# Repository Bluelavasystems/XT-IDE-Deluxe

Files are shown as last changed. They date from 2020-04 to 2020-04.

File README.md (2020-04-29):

Blue lava systems XT-IDE Deluxe ReadMe
----

Bootable 8-bit ISA CF+IDE interface

Documentation for the switches can be found on the rear silkscreen.

Credit:
----
Design by monotech pcs

Design uses some of the schematic from XT-IDE Rev2 and Glitchworks
www.vcfed.org/forum/showthread.php?29202-XTIDE-Rev2
github.com/glitchwrks/xt_ide

XT-IDE Universal BIOS
www.xtideuniversalbios.org

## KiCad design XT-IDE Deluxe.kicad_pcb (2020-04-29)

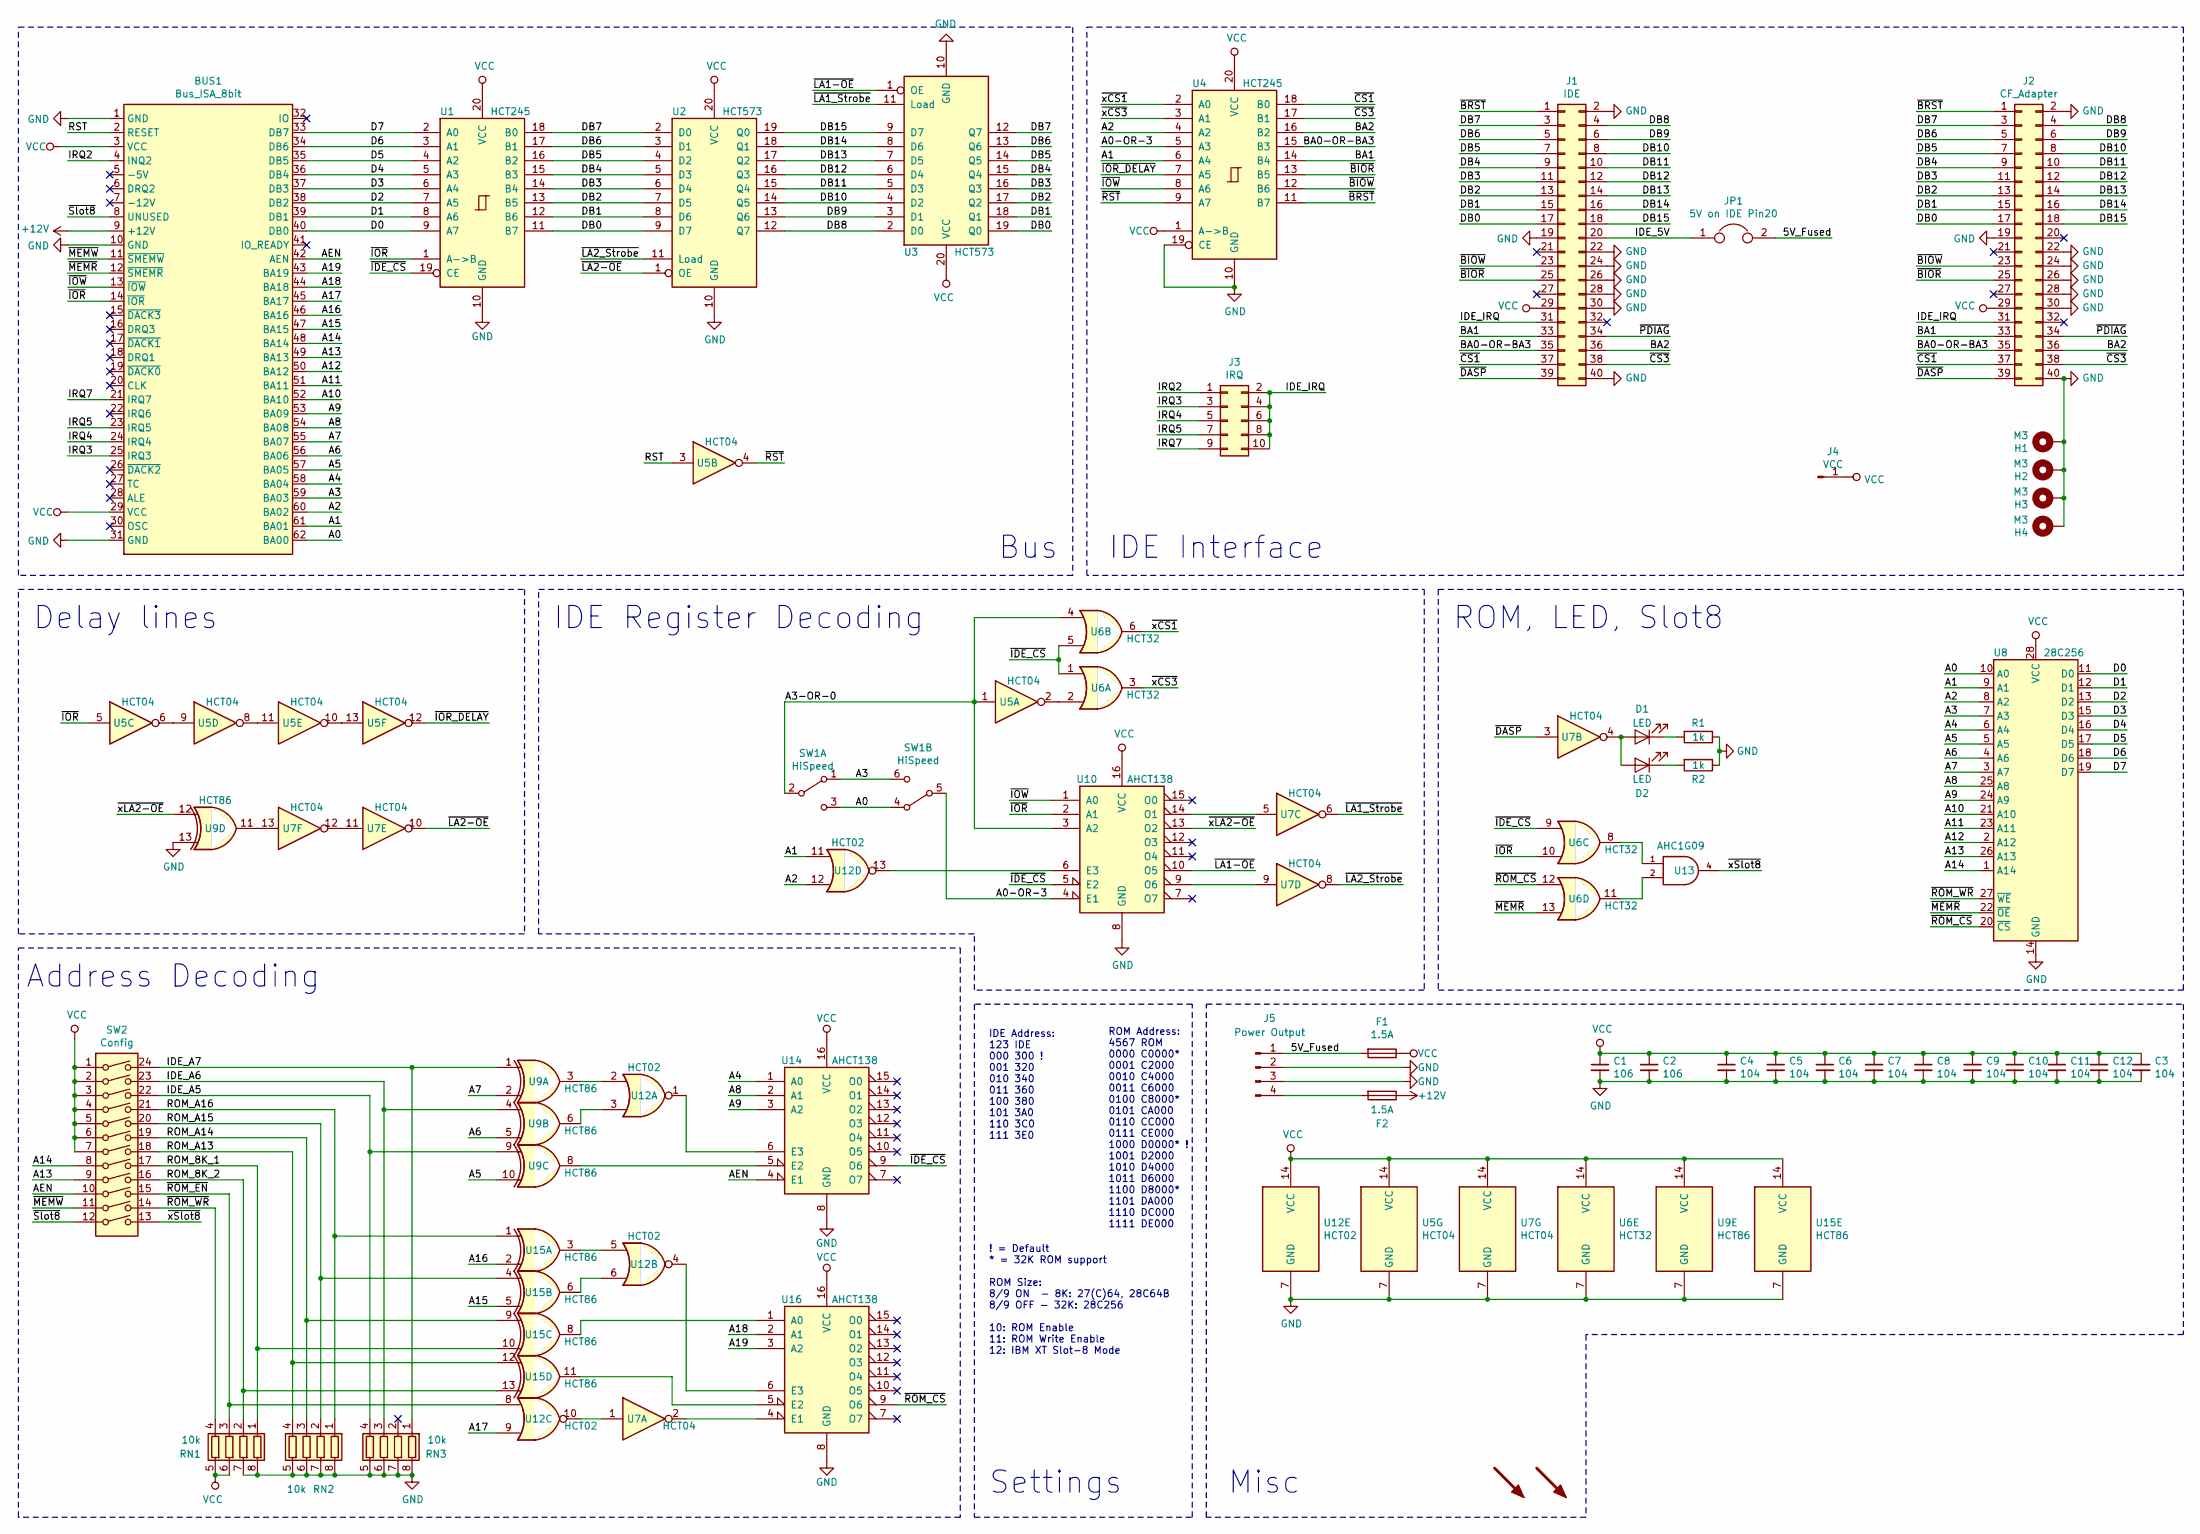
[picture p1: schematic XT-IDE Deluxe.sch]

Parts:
BUS1: Bus_ISA_8bit; ISA-8BIT-XT-IDE
C1, C2: 106; C_0805_2012Metric
C3, C4, C5, C6, C7, C8, C9, C10, C11, C12: 104; C_0805_2012Metric
D1: LED; LED_0805_2012Metric
D2: LED; PinHeader_1x02_P2.54mm_Horizontal
F1, F2: 1.5A; Fuse_1206_3216Metric; LCSC C182309
H1, H2, H3, H4: M3; MountingHole_3.2mm_M3_Pad
J1: IDE; IDC-Header_2x20_P2.54mm_Horizontal
J2: CF_Adapter; PinSocket_2x20_P2.54mm_Vertical
J3: IRQ; PinHeader_2x05_P2.54mm_Vertical
J4: VCC; PinHeader_1x01_P2.54mm_Vertical
J5: Power Output; PinHeader_1x04_P2.54mm_Horizontal
JP1: 5V on IDE Pin20; PinHeader_1x02_P2.54mm_Vertical
LOGO1: SYM_Arrow45_Large; Monotech Logo 12mm
LOGO2: SYM_Arrow45_Large; XT-IDE Deluxe
R1, R2: 1k; R_0805_2012Metric
RN1, RN2, RN3: 10k; R_Array_Convex_4x0603
SW1: HiSpeed; SW_MS-22D18G2
SW2: Config; SW_DIP_SPSTx12_Slide_9.78x32.66mm_W7.62mm_P2.54mm
U1, U4: HCT245; TSSOP-20_4.4x6.5mm_P0.65mm
U2, U3: HCT573; SOIC-20W_7.5x12.8mm_P1.27mm
U5, U7: HCT04; SOIC-14_3.9x8.7mm_P1.27mm
U6: HCT32; SOIC-14_3.9x8.7mm_P1.27mm
U8: 28C256; DIP-28_W15.24mm_Socket
U9, U15: HCT86; SOIC-14_3.9x8.7mm_P1.27mm
U10, U14, U16: AHCT138; SOIC-16_3.9x9.9mm_P1.27mm
U12: HCT02; SOIC-14_3.9x8.7mm_P1.27mm
U13: AHC1G09; SOT-353_SC-70-5

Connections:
+12V: BUS1.9 (+12V), F2.1
/5V_Fused: F1.2, J5.1, JP1.2
/A0: BUS1.62 (BA00), SW1.3 (C), SW1.4 (A), U8.10 (A0)
/A0-OR-3: SW1.5 (B), U4.5 (A3), U10.4 (E1)
/A1: BUS1.61 (BA01), U4.6 (A4), U8.9 (A1), U12.11
/A2: BUS1.60 (BA02), U4.4 (A2), U8.8 (A2), U12.12
/A3: BUS1.59 (BA03), SW1.1 (A), SW1.6 (C), U8.7 (A3)
/A3-OR-0: SW1.2 (B), U5.1, U6.4, U10.3 (A2)
/A4: BUS1.58 (BA04), U8.6 (A4), U14.1 (A0)
/A5: BUS1.57 (BA05), U8.5 (A5), U9.10
/A6: BUS1.56 (BA06), U8.4 (A6), U9.5
/A7: BUS1.55 (BA07), U8.3 (A7), U9.2
/A8: BUS1.54 (BA08), U8.25 (A8), U14.2 (A1)
/A9: BUS1.53 (BA09), U8.24 (A9), U14.3 (A2)
/A10: BUS1.52 (BA10), U8.21 (A10)
/A11: BUS1.51 (BA11), U8.23 (A11)
/A12: BUS1.50 (BA12), U8.2 (A12)
/A13: BUS1.49 (BA13), SW2.9, U8.26 (A13)
/A14: BUS1.48 (BA14), SW2.8, U8.1 (A14)
/A15: BUS1.47 (BA15), U15.5
/A16: BUS1.46 (BA16), U15.2
/A17: BUS1.45 (BA17), U12.9
/A18: BUS1.44 (BA18), U16.2 (A1)
/A19: BUS1.43 (BA19), U16.3 (A2)
/AEN: BUS1.42 (AEN), SW2.10, U14.4 (E1)
/BA0-OR-BA3: J1.35, J2.35, U4.15 (B3)
/BA1: J1.33, J2.33, U4.14 (B4)
/BA2: J1.36, J2.36, U4.16 (B2)
/D0: BUS1.40 (DB0), U1.9 (A7), U8.11 (D0)
/D1: BUS1.39 (DB1), U1.8 (A6), U8.12 (D1)
/D2: BUS1.38 (DB2), U1.7 (A5), U8.13 (D2)
/D3: BUS1.37 (DB3), U1.6 (A4), U8.15 (D3)
/D4: BUS1.36 (DB4), U1.5 (A3), U8.16 (D4)
/D5: BUS1.35 (DB5), U1.4 (A2), U8.17 (D5)
/D6: BUS1.34 (DB6), U1.3 (A1), U8.18 (D6)
/D7: BUS1.33 (DB7), U1.2 (A0), U8.19 (D7)
/DB0: J1.17, J2.17, U1.11 (B7), U2.9 (D7), U3.19 (Q0)
/DB1: J1.15, J2.15, U1.12 (B6), U2.8 (D6), U3.18 (Q1)
/DB2: J1.13, J2.13, U1.13 (B5), U2.7 (D5), U3.17 (Q2)
/DB3: J1.11, J2.11, U1.14 (B4), U2.6 (D4), U3.16 (Q3)
/DB4: J1.9, J2.9, U1.15 (B3), U2.5 (D3), U3.15 (Q4)
/DB5: J1.7, J2.7, U1.16 (B2), U2.4 (D2), U3.14 (Q5)
/DB6: J1.5, J2.5, U1.17 (B1), U2.3 (D1), U3.13 (Q6)
/DB7: J1.3, J2.3, U1.18 (B0), U2.2 (D0), U3.12 (Q7)
/DB8: J1.4, J2.4, U2.12 (Q7), U3.2 (D0)
/DB9: J1.6, J2.6, U2.13 (Q6), U3.3 (D1)
/DB10: J1.8, J2.8, U2.14 (Q5), U3.4 (D2)
/DB11: J1.10, J2.10, U2.15 (Q4), U3.5 (D3)
/DB12: J1.12, J2.12, U2.16 (Q3), U3.6 (D4)
/DB13: J1.14, J2.14, U2.17 (Q2), U3.7 (D5)
/DB14: J1.16, J2.16, U2.18 (Q1), U3.8 (D6)
/DB15: J1.18, J2.18, U2.19 (Q0), U3.9 (D7)
/IDE_5V: J1.20, JP1.1
/IDE_A5: RN3.4 (R4.1), SW2.22, U9.9
/IDE_A6: RN3.3 (R3.1), SW2.23, U9.4
/IDE_A7: RN3.1 (R1.1), SW2.24, U9.1
/IDE_IRQ: J1.31, J2.31, J3.2, J3.4, J3.6, J3.8, J3.10
/IRQ2: BUS1.4 (INQ2), J3.1
/IRQ3: BUS1.25 (IRQ3), J3.3
/IRQ4: BUS1.24 (IRQ4), J3.5
/IRQ5: BUS1.23 (IRQ5), J3.7
/IRQ7: BUS1.21 (IRQ7), J3.9
/ROM_8K_1: RN1.1 (R1.1), SW2.17, U15.10
/ROM_8K_2: RN1.2 (R2.1), SW2.16, U15.13
/ROM_A13: RN2.4 (R4.1), SW2.18, U15.12
/ROM_A14: RN2.3 (R3.1), SW2.19, U15.9
/ROM_A15: RN2.2 (R2.1), SW2.20, U15.4
/ROM_A16: RN2.1 (R1.1), SW2.21, U15.1
/RST: BUS1.2 (RESET), U5.3
/~BIOR: J1.25, J2.25, U4.13 (B5)
/~BIOW: J1.23, J2.23, U4.12 (B6)
/~BRST: J1.1, J2.1, U4.11 (B7)
/~CS1: J1.37, J2.37, U4.18 (B0)
/~CS3: J1.38, J2.38, U4.17 (B1)
/~DASP: J1.39, J2.39, U7.3
/~IDE_CS: U1.19 (CE), U6.1, U6.5, U6.9, U10.5 (E2), U14.9 (O6)
/~IOR: BUS1.14 (~IOR), U1.1 (A->B), U5.5, U6.10, U10.2 (A1)
/~IOR_DELAY: U4.7 (A5), U5.12
/~IOW: BUS1.13 (~IOW), U4.8 (A6), U10.1 (A0)
/~LA1-OE: U3.1 (OE), U10.10 (O5)
/~LA1_Strobe: U3.11 (Load), U7.6
/~LA2-OE: U2.1 (OE), U7.10
/~LA2_Strobe: U2.11 (Load), U7.8
/~MEMR: BUS1.12 (~SMEMR), U6.13, U8.22 (~OE)
/~MEMW: BUS1.11 (~SMEMW), SW2.11
/~PDIAG: J1.34, J2.34
/~ROM_CS: U6.12, U8.20 (~CS), U16.9 (O6)
/~ROM_EN: RN1.3 (R3.1), SW2.15, U12.8
/~ROM_WR: RN1.4 (R4.1), SW2.14, U8.27 (~WE)
/~RST: U4.9 (A7), U5.4
/~Slot8: BUS1.8 (UNUSED), SW2.12
/~xCS1: U4.2 (A0), U6.6
/~xCS3: U4.3 (A1), U6.3
/~xLA2-OE: U9.12, U10.13 (O2)
/~xSlot8: SW2.13, U13.4
GND: BUS1.1 (GND), BUS1.10 (GND), BUS1.31 (GND), C1.2, C2.2, C3.2, C4.2, C5.2, C6.2, C7.2, C8.2, C9.2, C10.2, C11.2, C12.2, H1.1, H2.1, H3.1, H4.1, J1.2, J1.19, J1.22, J1.24, J1.26, J1.28, J1.30, J1.40, J2.2, J2.19, J2.22, J2.24, J2.26, J2.28, J2.30, J2.40, J5.2, J5.3, R1.1, R2.1, RN1.7 (R2.2), RN1.8 (R1.2), RN2.5 (R4.2), RN2.6 (R3.2), RN2.7 (R2.2), RN2.8 (R1.2), RN3.5 (R4.2), RN3.6 (R3.2), RN3.7 (R2.2), RN3.8 (R1.2), U1.10 (GND), U2.10 (GND), U3.10 (GND), U4.10 (GND), U4.19 (CE), U5.7 (GND), U6.7 (GND), U7.7 (GND), U8.14 (GND), U9.7 (GND), U9.13, U10.8 (GND), U12.7 (GND), U13.3 (GND), U14.8 (GND), U15.7 (GND), U16.8 (GND)
unnamed: D1.1 (K), R1.2
unnamed: D1.2 (A), D2.2 (A), U7.4
unnamed: D2.1 (K), R2.2
unnamed: F2.2, J5.4
unnamed: U5.2, U6.2
unnamed: U5.6, U5.9
unnamed: U5.10, U5.13
unnamed: U5.8, U5.11
unnamed: U7.11, U7.12
unnamed: U7.13, U9.11
unnamed: U10.6 (E3), U12.13
unnamed: U7.9, U10.9 (O6)
unnamed: U7.5, U10.14 (O1)
unnamed: U12.1, U14.6 (E3)
unnamed: U9.3, U12.2
unnamed: U9.6, U12.3
unnamed: U12.4, U16.6 (E3)
unnamed: U12.5, U15.3
unnamed: U12.6, U15.6
unnamed: U7.1, U12.10
unnamed: U6.8, U13.1
unnamed: U6.11, U13.2
unnamed: U9.8, U14.5 (E2)
unnamed: U15.8, U16.1 (A0)
unnamed: U15.11, U16.5 (E2)
unnamed: U7.2, U16.4 (E1)
VCC: BUS1.3 (VCC), BUS1.29 (VCC), C1.1, C2.1, C3.1, C4.1, C5.1, C6.1, C7.1, C8.1, C9.1, C10.1, C11.1, C12.1, F1.1, J1.29, J2.29, J4.1, RN1.5 (R4.2), RN1.6 (R3.2), SW2.1, SW2.2, SW2.3, SW2.4, SW2.5, SW2.6, SW2.7, U1.20 (VCC), U2.20 (VCC), U3.20 (VCC), U4.1 (A->B), U4.20 (VCC), U5.14 (VCC), U6.14 (VCC), U7.14 (VCC), U8.28 (VCC), U9.14 (VCC), U10.16 (VCC), U12.14 (VCC), U13.5 (VCC), U14.16 (VCC), U15.14 (VCC), U16.16 (VCC)

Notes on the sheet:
Address Decoding
IDE Address: 123 IDE 000 300 ! 001 320 010 340 011 360 100 380 101 3A0 110 3C0 111 3E0 ! = Default * = 32K ROM support ROM Size: 8/9 ON - 8K: 27(C)64, 28C64B 8/9 OFF - 32K: 28C256 10: ROM Enable 11: ROM Write Enable 12: IBM XT Slot-8 Mode
Delay lines
Bus
IDE Interface
Misc
ROM, LED, Slot8
Settings
IDE Register Decoding
ROM Address: 4567 ROM 0000 C0000* 0001 C2000 0010 C4000 0011 C6000 0100 C8000* 0101 CA000 0110 CC000 0111 CE000 1000 D0000* ! 1001 D2000 1010 D4000 1011 D6000 1100 D8000* 1101 DA000 1110 DC000 1111 DE000

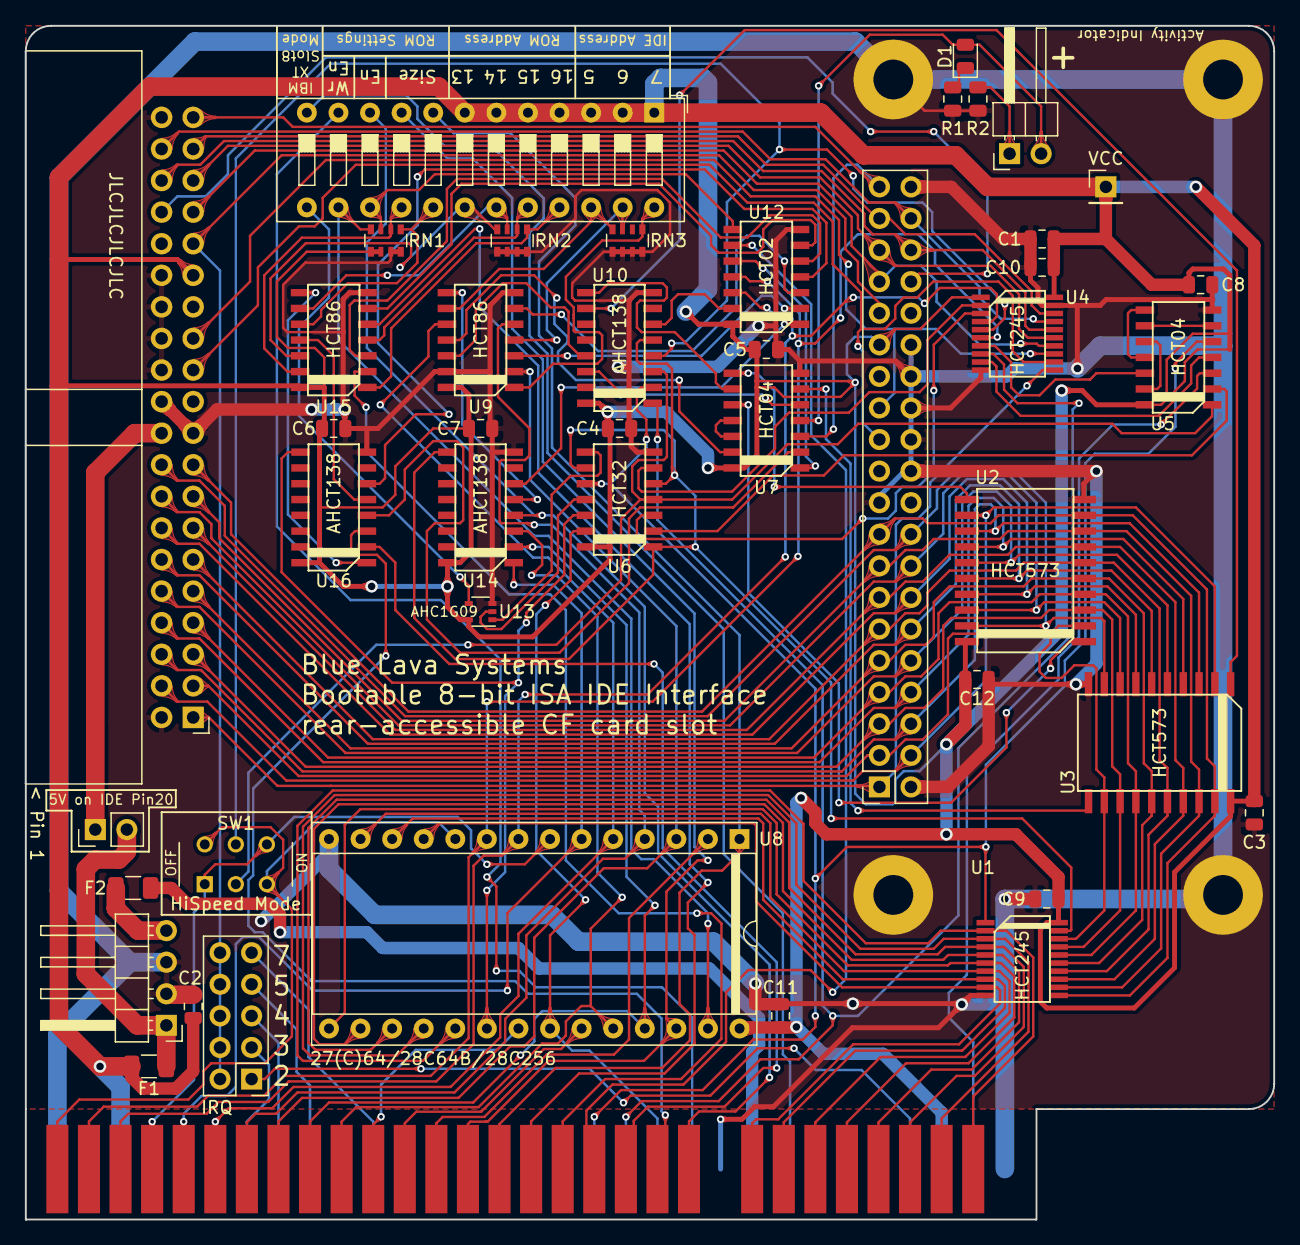
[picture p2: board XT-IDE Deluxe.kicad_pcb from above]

Board: 2 copper layers, 100.4 x 96.0 mm, 49 parts (0 on the bottom side), 123 nets.
